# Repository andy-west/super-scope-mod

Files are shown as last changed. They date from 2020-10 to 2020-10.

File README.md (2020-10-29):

# super-scope-mod
Tracking, BT communication code, and 3D printer files to make SNES Super Scope work on LCD TVs

## Description
This is the companion code for *element14 Presents* episode 469: "Nintendo Super Scope Mod For Modern Televisions".

Nintendo Super Scope Mod For Modern Televisions (https://www.youtube.com/watch?v=_CQ7ApMLAM0)
 
element14 Community page: https://www.element14.com/community/docs/DOC-95663

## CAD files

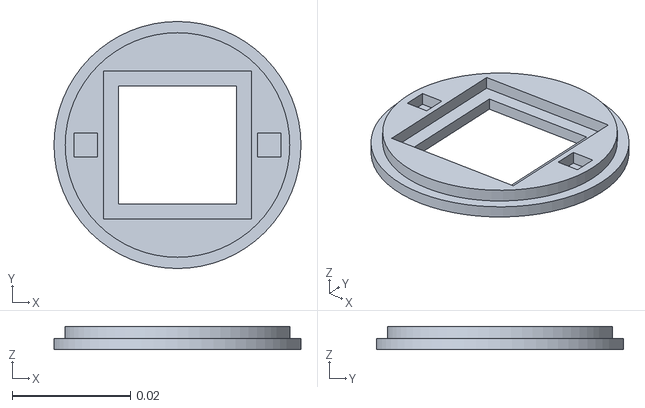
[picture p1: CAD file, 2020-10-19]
3D-models/optical-mount-1.stl
0.0418 x 0.0418 x 0.0039

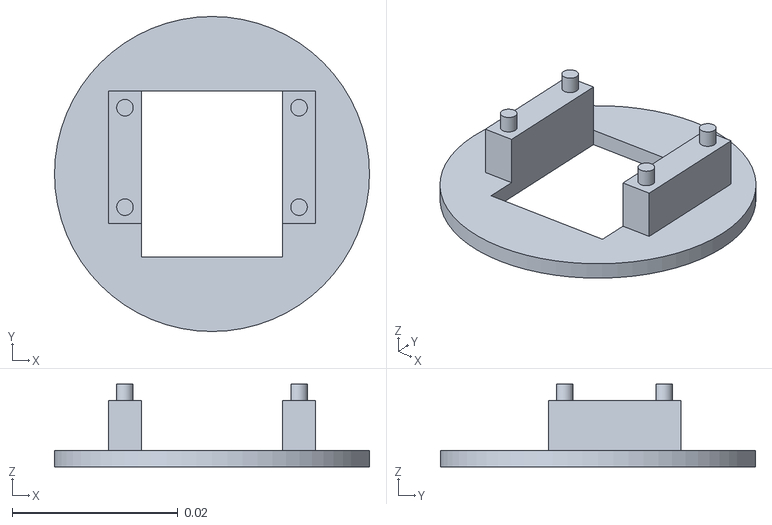
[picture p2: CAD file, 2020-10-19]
3D-models/optical-mount-2.stl
0.038 x 0.038 x 0.01

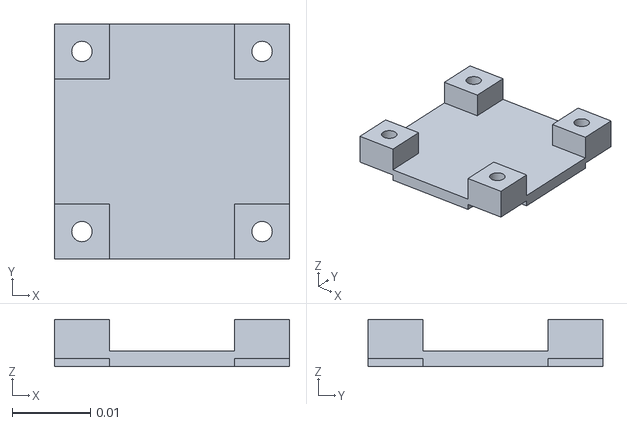
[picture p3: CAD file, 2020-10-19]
3D-models/fan-shroud.stl
0.03 x 0.03 x 0.006

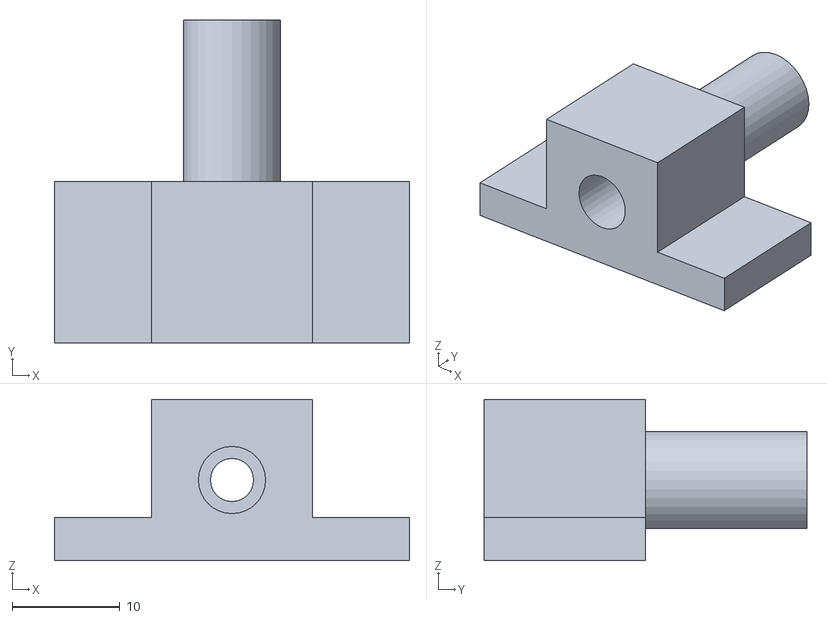
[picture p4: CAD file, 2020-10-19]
3D-models/led-holder.stl
33.0 x 30.0 x 15.0

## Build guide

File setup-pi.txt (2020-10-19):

Here are the steps to configure the Raspberry Pi for this mod.

1) Install OS and updates.

BT setup:

2) Add Bluetooth device and pair.
3) "hcitool scan" to get mac address of the device.
4) sudo nano /etc/rc.local
5) Add "sudo rfcomm bind 0 <MAC address> 1" before exit 0. Replace <MAC address> with address of the BT adapter.
6) Restart.
7) sudo apt-get install minicom
8) minicom -D /dev/rfcomm0
9) CTRL-A X to exit minicom.

Camera setup:

10) sudo raspi-config
11) Enable camera and finish.
12) pip install "picamera[array]"

13) pip install imutils
14) pip install scipy

For the power LED:

15) Enable serial in raspi-config for power LED.

Use this to run super-scope.py on startup:

16) https://raspberrypi.stackexchange.com/a/79667

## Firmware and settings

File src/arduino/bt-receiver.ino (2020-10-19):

//#include <SoftwareSerial.h>
#include <NeoSWSerial.h>

const int COMPOSITE_SYNC_PIN = 2;
const int VERTICAL_SYNC_PIN = 3;

const int BLUETOOTH_RX_PIN = 4;
const int BLUETOOTH_TX_PIN = 5;

const int TRIGGER_PIN = 8;
const int CURSOR_PIN = 9;
const int TURBO_PIN = 10;
const int PAUSE_PIN = 11;
const int EXTERNAL_LATCH_PIN = 12;  // Raster gate

const byte BT_MESSAGE_TRIGGER_PRESSED = 231;
const byte BT_MESSAGE_TRIGGER_RELEASED = 232;
const byte BT_MESSAGE_CURSOR_PRESSED = 233;
const byte BT_MESSAGE_CURSOR_RELEASED = 234;
const byte BT_MESSAGE_TURBO_ENABLED = 235;
const byte BT_MESSAGE_TURBO_DISABLED = 236;
const byte BT_MESSAGE_PAUSE_PRESSED = 237;
const byte BT_MESSAGE_PAUSE_RELEASED = 238;
const byte BT_MESSAGE_TV_NOT_VISIBLE = 239;
const byte BT_MESSAGE_AIM_X = 240;
const byte BT_MESSAGE_AIM_Y = 241;

const byte BT_MESSAGE_NONE = 0;
byte lastBluetoothMessage = BT_MESSAGE_NONE;

bool isTriggerPressed = false;
bool isCursorPressed = false;
bool isTurboEnabled = false;
bool isPausePressed = false;
bool isTvVisible = false;

const int minAimLine = 10;
const int maxAimLine = 240;
const int minAimMicroseconds = 5;
const int maxAimMicroseconds = 55;

int aimLine = (maxAimLine - minAimLine + 1) / 2 + minAimLine;
int aimMicroseconds = (maxAimMicroseconds - minAimMicroseconds + 1) / 2 + minAimMicroseconds;

volatile int currentLine = 0;

//SoftwareSerial bluetoothSerial(BLUETOOTH_RX_PIN, BLUETOOTH_TX_PIN);
NeoSWSerial bluetoothSerial(BLUETOOTH_RX_PIN, BLUETOOTH_TX_PIN);

void setup() {
  bluetoothSerial.begin(9600);
  Serial.begin(9600);

  pinMode(COMPOSITE_SYNC_PIN, INPUT);
  pinMode(VERTICAL_SYNC_PIN, INPUT);

  pinMode(TRIGGER_PIN, OUTPUT);
  pinMode(CURSOR_PIN, OUTPUT);
  pinMode(TURBO_PIN, OUTPUT);
  pinMode(PAUSE_PIN, OUTPUT);
  pinMode(EXTERNAL_LATCH_PIN, OUTPUT);

  digitalWrite(TRIGGER_PIN, HIGH);
  digitalWrite(CURSOR_PIN, HIGH);
  digitalWrite(TURBO_PIN, HIGH);
  digitalWrite(PAUSE_PIN, HIGH);
  digitalWrite(EXTERNAL_LATCH_PIN, HIGH);

  attachInterrupt(digitalPinToInterrupt(COMPOSITE_SYNC_PIN), handleCompositeSync, RISING);
  attachInterrupt(digitalPinToInterrupt(VERTICAL_SYNC_PIN), handleVerticalSync, RISING);

  Serial.println("Super Scope BT receiver started.");
}

void loop() {
  if (bluetoothSerial.available() > 0) {
    int inputByte = bluetoothSerial.read();

    switch (inputByte) {
      case BT_MESSAGE_TRIGGER_PRESSED:
        digitalWrite(TRIGGER_PIN, LOW);
        Serial.println("Trigger pressed.");
        break;
      case BT_MESSAGE_TRIGGER_RELEASED:
        digitalWrite(TRIGGER_PIN, HIGH);
        Serial.println("Trigger released.");
        break;
      case BT_MESSAGE_CURSOR_PRESSED:
        digitalWrite(CURSOR_PIN, LOW);
        Serial.println("Cursor pressed.");
        break;
      case BT_MESSAGE_CURSOR_RELEASED:
        digitalWrite(CURSOR_PIN, HIGH);
        Serial.println("Cursor released.");
        break;
      case BT_MESSAGE_TURBO_ENABLED:
        digitalWrite(TURBO_PIN, LOW);
        Serial.println("Turbo enabled.");
        break;
      case BT_MESSAGE_TURBO_DISABLED:
        digitalWrite(TURBO_PIN, HIGH);
        Serial.println("Turbo disabled.");
        break;
      case BT_MESSAGE_PAUSE_PRESSED:
        digitalWrite(PAUSE_PIN, LOW);
        Serial.println("Pause pressed.");
        break;
      case BT_MESSAGE_PAUSE_RELEASED:
        digitalWrite(PAUSE_PIN, HIGH);
        Serial.println("Pause pressed.");
        break;
      case BT_MESSAGE_TV_NOT_VISIBLE:
        isTvVisible = false;
        break;
      case BT_MESSAGE_AIM_X:
      case BT_MESSAGE_AIM_Y:
        isTvVisible = true;
        break;
    }

    if (inputByte > 230) {
      lastBluetoothMessage = inputByte;
    }
    else {
      switch (lastBluetoothMessage) {
        case BT_MESSAGE_AIM_X:
          aimMicroseconds = inputByte + minAimMicroseconds;
          break;
        case BT_MESSAGE_AIM_Y:
          aimLine = inputByte + minAimLine;
          break;
      }
    }
  }
}

void handleCompositeSync() {
  currentLine++;
  
  if (isTvVisible && currentLine == aimLine) {
    delayMicroseconds(aimMicroseconds);
    digitalWrite(EXTERNAL_LATCH_PIN, LOW);
    delayMicroseconds(5);
    digitalWrite(EXTERNAL_LATCH_PIN, HIGH);
  }
}

void handleVerticalSync() {
  currentLine = 0;
}

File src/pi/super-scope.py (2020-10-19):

import cv2
import numpy
import os
import RPi.GPIO as GPIO
import time
import serial

from imutils import perspective

TRACKING_WIDTH = 51
BLACK_BAR_WIDTH = 8
WIDE_TRACKING_WIDTH = TRACKING_WIDTH + BLACK_BAR_WIDTH * 2
TRACKING_HEIGHT = 231

TURBO_PIN = 5
POWER_ON_PIN = 6
PAUSE_BUTTON_PIN = 13
TRIGGER_BUTTON_PIN = 19
CURSOR_BUTTON_PIN = 26

BT_MESSAGE_TRIGGER_PRESSED = 231
BT_MESSAGE_TRIGGER_RELEASED = 232
BT_MESSAGE_CURSOR_PRESSED = 233
BT_MESSAGE_CURSOR_RELEASED = 234
BT_MESSAGE_TURBO_ENABLED = 235
BT_MESSAGE_TURBO_DISABLED = 236
BT_MESSAGE_PAUSE_PRESSED = 237
BT_MESSAGE_PAUSE_RELEASED = 238
BT_MESSAGE_TV_NOT_VISIBLE = 239
BT_MESSAGE_AIM_X = 240
BT_MESSAGE_AIM_Y = 241

isTvVisible = False

GPIO.setmode(GPIO.BCM)

GPIO.setup(TURBO_PIN, GPIO.IN, pull_up_down=GPIO.PUD_DOWN)
GPIO.setup(POWER_ON_PIN, GPIO.IN, pull_up_down=GPIO.PUD_DOWN)
GPIO.setup(PAUSE_BUTTON_PIN, GPIO.IN, pull_up_down=GPIO.PUD_DOWN)
GPIO.setup(TRIGGER_BUTTON_PIN, GPIO.IN, pull_up_down=GPIO.PUD_DOWN)
GPIO.setup(CURSOR_BUTTON_PIN, GPIO.IN, pull_up_down=GPIO.PUD_DOWN)

serialPort = serial.Serial(port = "/dev/rfcomm0")

def handleButtons(channel):
    isRising = GPIO.input(channel)

    if channel == TURBO_PIN:
        serialPort.write(bytearray([BT_MESSAGE_TURBO_ENABLED]) if isRising else bytearray([BT_MESSAGE_TURBO_DISABLED]))
    elif channel == POWER_ON_PIN:
        if not isRising:
            os.system("shutdown now -h")
    elif channel == PAUSE_BUTTON_PIN:
        serialPort.write(bytearray([BT_MESSAGE_PAUSE_PRESSED]) if isRising else bytearray([BT_MESSAGE_PAUSE_RELEASED]))
    elif channel == TRIGGER_BUTTON_PIN:
        serialPort.write(bytearray([BT_MESSAGE_TRIGGER_PRESSED]) if isRising else bytearray([BT_MESSAGE_TRIGGER_RELEASED]))
    elif channel == CURSOR_BUTTON_PIN:
        serialPort.write(bytearray([BT_MESSAGE_CURSOR_PRESSED]) if isRising else bytearray([BT_MESSAGE_CURSOR_RELEASED]))

handleButtons(TURBO_PIN)

GPIO.add_event_detect(TURBO_PIN, GPIO.BOTH, callback = handleButtons, bouncetime = 10)
GPIO.add_event_detect(POWER_ON_PIN, GPIO.BOTH, callback = handleButtons, bouncetime = 10)
GPIO.add_event_detect(PAUSE_BUTTON_PIN, GPIO.BOTH, callback = handleButtons, bouncetime = 10)
GPIO.add_event_detect(TRIGGER_BUTTON_PIN, GPIO.BOTH, callback = handleButtons, bouncetime = 10)
GPIO.add_event_detect(CURSOR_BUTTON_PIN, GPIO.BOTH, callback = handleButtons, bouncetime = 10)

camera = cv2.VideoCapture(0)

if camera.isOpened():
    camera.set(cv2.CAP_PROP_FRAME_WIDTH, 640)
    camera.set(cv2.CAP_PROP_FRAME_HEIGHT, 480)

windowName = "Super Scope"
cv2.namedWindow(windowName)

while True:
    wasFrameGrabSuccessful, frame = camera.read()

    if wasFrameGrabSuccessful:
        grayFrame = cv2.cvtColor(frame, cv2.COLOR_BGR2GRAY)
        _, threshold = cv2.threshold(grayFrame, 127, 255, cv2.THRESH_BINARY)
        contours, _ = cv2.findContours(threshold, cv2.RETR_TREE, cv2.CHAIN_APPROX_SIMPLE)

        finalFrame = cv2.cvtColor(grayFrame, cv2.COLOR_GRAY2BGR)

        trackingPointCount = 0
        trackingPoints = numpy.zeros(shape = (4, 2), dtype = numpy.float32)

        for contour in contours:
            moments = cv2.moments(contour)

            if moments["m00"] > 10:
                if trackingPointCount < 5:
                    centerX = int(moments["m10"] / moments["m00"])
                    centerY = int(moments["m01"] / moments["m00"])
                    trackingPoints[trackingPointCount] = [centerX, centerY]
                    cv2.circle(finalFrame, (centerX, centerY), 5, (0, 255, 0), cv2.FILLED)

                trackingPointCount += 1

        trackingPoints = perspective.order_points(trackingPoints)

        # Draw red dot at center.
        cv2.circle(finalFrame, (320, 240), 5, (0, 0, 255), cv2.FILLED)

        # Outline transformed area in blue.
        cv2.rectangle(finalFrame, (0, 0), (TRACKING_WIDTH, TRACKING_HEIGHT), (255, 0, 0), 3)

        if trackingPointCount == 4:
            destPoints = numpy.array([[0, 0], [WIDE_TRACKING_WIDTH - 1, 0], [WIDE_TRACKING_WIDTH - 1, TRACKING_HEIGHT - 1], [0, TRACKING_HEIGHT - 1]], dtype = numpy.float32)
            transform = cv2.getPerspectiveTransform(trackingPoints[:, numpy.newaxis, :], destPoints[:, numpy.newaxis, :])
            transformed = cv2.perspectiveTransform(numpy.array([[320, 240]], dtype = numpy.float32)[:, numpy.newaxis, :], transform)

            transformedX = int(transformed[0][0][0] - BLACK_BAR_WIDTH)
            transformedY = int(transformed[0][0][1])

            # Draw transformed tracking point in yellow.
            cv2.circle(finalFrame, (transformedX, transformedY), 5, (0, 255, 255), cv2.FILLED)

            if (0 <= transformedX < TRACKING_WIDTH) and (0 <= transformedY < TRACKING_HEIGHT):
                isTvVisible = True;
                serialPort.write(bytearray([BT_MESSAGE_AIM_X, transformedX, BT_MESSAGE_AIM_Y, transformedY]))
            elif isTvVisible:
                isTvVisible = False;
                serialPort.write(bytearray([BT_MESSAGE_TV_NOT_VISIBLE]))
        elif isTvVisible:
            isTvVisible = False;
            serialPort.write(bytearray([BT_MESSAGE_TV_NOT_VISIBLE]))

        cv2.imshow(windowName, finalFrame)

    if cv2.waitKey(1) % 0xFF == 27:  # Escape key
        break

camera.release()
cv2.destroyAllWindows()
GPIO.cleanup()
